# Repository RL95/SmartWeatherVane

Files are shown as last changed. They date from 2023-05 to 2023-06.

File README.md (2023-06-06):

# Smart Weather Vane (project SAFE)
A smart weather vane used for mounting various sensors on rooftops.

The project was developped at the [The University of Applied Sciences and Arts of Western Switzerland](https://www.hesge.ch/hepia/groupe/aero-nautique-spatiale)(HEPIA) for the project [SAFE (Simulator of Autonomous Flight Environments)](https://www.hesge.ch/hepia/recherche-developpement/projets-recherche/safe-0), which aims to measure and replicate atmospheric turbulence at drone scale in an autonomous flight environment simulator for drone certification.

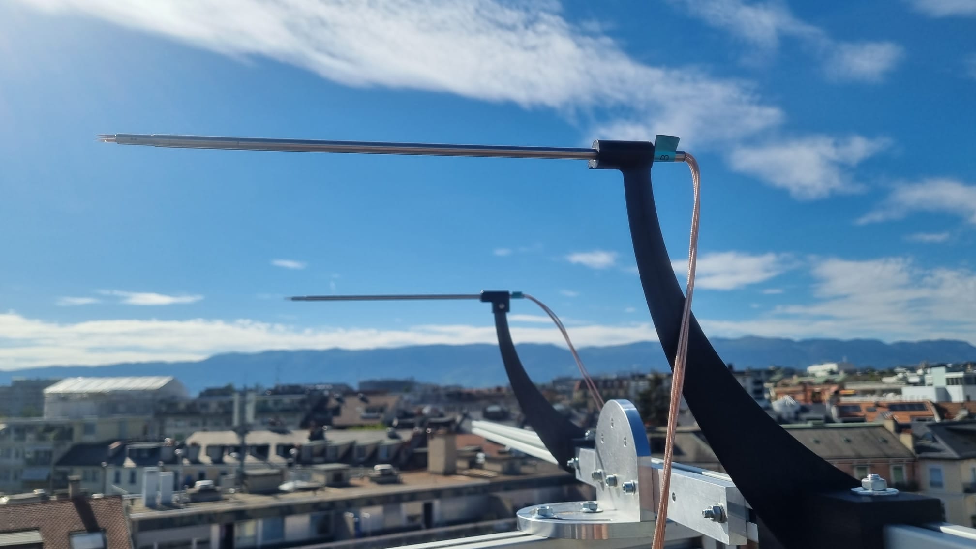
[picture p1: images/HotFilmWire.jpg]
HotFilmWire

(image © M. Jourdain de Thieulloy)

## Firmware
### Description
The control firmware will be running on a NucleoF401RE.

> **Note**
> Firmware implementation is in progress

### Development platform
The firmware is developped with [STM32CUBEIDE](https://www.st.com/en/development-tools/stm32cubeide.html)

### Dependencies
> **Note**
> None for now :)

## Hardware list

|Item|QTY| Ref. Mfr |Ref. Sup. |Supplier |Description/link |
|:--:|:-:|:---:|:---:|:---:|:---:|
|1 |1  |103H7823-5740 |302-23-838 |Distrelec  |[Stepper motor ](https://www.distrelec.ch/en/stepper-motor-7nm-2300min-sup-sup-nema-24-sanyo-denki-103h7823-5740/p/30223838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)|
|2 |1  |PMT-24V200W2BR |303-72-090 |Distrelec  |[SPSU 24V ](https://www.distrelec.ch/en/switched-mode-power-supply-211-2w-24v-8a-delta-electronics-pmt-24v200w2br/p/30372090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)|
|3 |1  |B14HD-L-254-B-4 |301-34-501 |Distrelec  |[Solenoid ](https://www.distrelec.ch/en/metric-pull-latching-open-frame-solenoid-24vdc-22w-12-7mm-27-5ohm-ledex-b14hd-254/p/30134501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)|
|4 |1  |TMC2660-BOB |301-62-143 |Distrelec  |[TMC2660 Driver ](https://www.distrelec.ch/en/stepper-driver-breakout-board-for-tmc2660-28v-trinamic-tmc2660-bob/p/30162143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)|
|5 |1  |ICK SMD F 10 SA |175-58-893 |Distrelec  |[Heatsink ](https://www.distrelec.ch/en/heat-sink-smd-71-fischer-elektronik-ick-smd-10-sa/p/17558893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)|
|6 |1  |N/A |22004-052512 |Norelem |[Pulley HTD 5M 12t ](https://www.norelem.ch/ch/en/Products/Product-overview/Systems-and-components-for-machine-and-plant-construction/Drive-technology/Toothed-belt-pulleys-Splined-shaft-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)|
|7 |1  |N/A |22004-052540 |Norelem |[Pulley HTD 5M 40t ](https://www.norelem.ch/ch/en/Products/Product-overview/Systems-and-components-for-machine-and-plant-construction/Drive-technology/Toothed-belt-pulleys-Splined-shaft-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)|
|8 |2  |N/A |24200-35207 |Norelem |[Mounted Bearing UC 207 ](https://www.norelem.ch/ch/en/Products/Product-overview/Systems-and-components-for-machine-and-plant-construction/Trapezoidal-thread-spindles-Ball-screw-linear-actuat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)|
|9 |1  |N/A |22062-0525X0300 |Norelem |[Belt HTD 5M 300mm ](https://www.norelem.ch/ch/en/Products/Product-overview/Systems-and-components-for-machine-and-plant-construction/Drive-technology/Toothed-belt-pulleys-Splined-shaft-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)|
|10  |1  |985-AS5048A-TS_EK_AB |AS5048A-TS_EK_AB |Mouser |[AS5048A hall encoder ](https://www.mouser.ch/ProductDetail/ams-OSRAM/AS5048A-TS_EK_AB?qs=Rt6VE0PE%2FOd5D%2Fkw9O7ofA%3D%3D)|
|11  |1  |N/A |633145 |Galaxus |[Disc brake disc & caliper ](https://www.galaxus.ch/en/s3/product/avid-ball-bearing-5-front-wheel-brake-disc-brakes-633145)|

> **Note**
> Nucleo F401RE must be added to table
>
> **Note**
> Aluminium extrusion used are yet to be listed in the table above
>
> **Note**
> Dibond plate must be added or replaced

## Preview of current CAD design
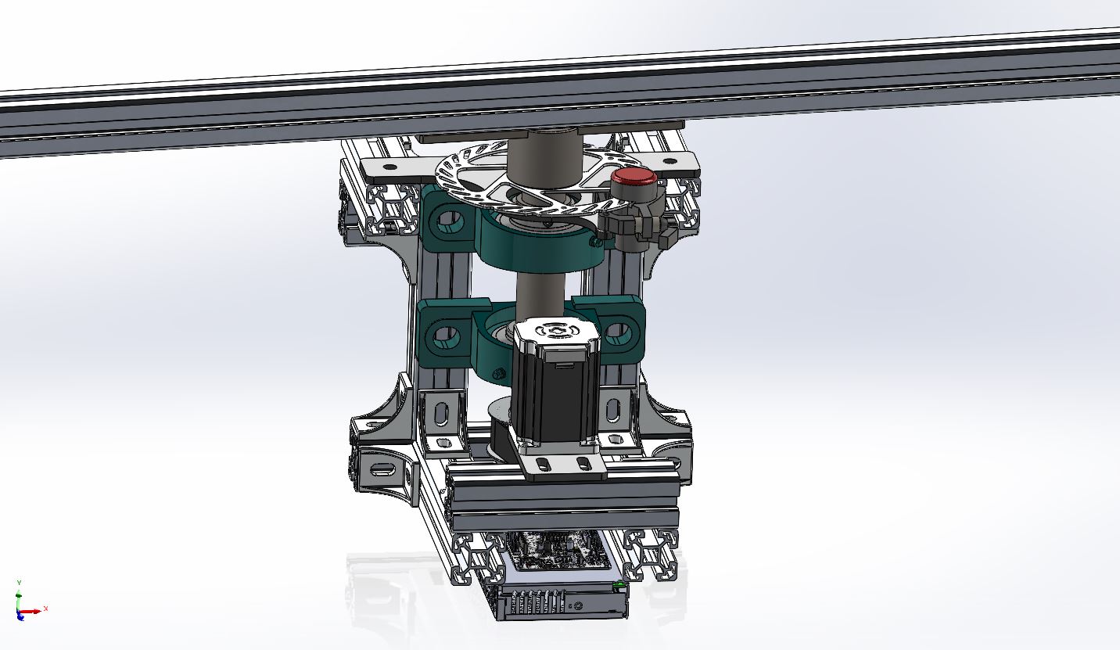
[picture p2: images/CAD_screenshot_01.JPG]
CAD_screenshot1


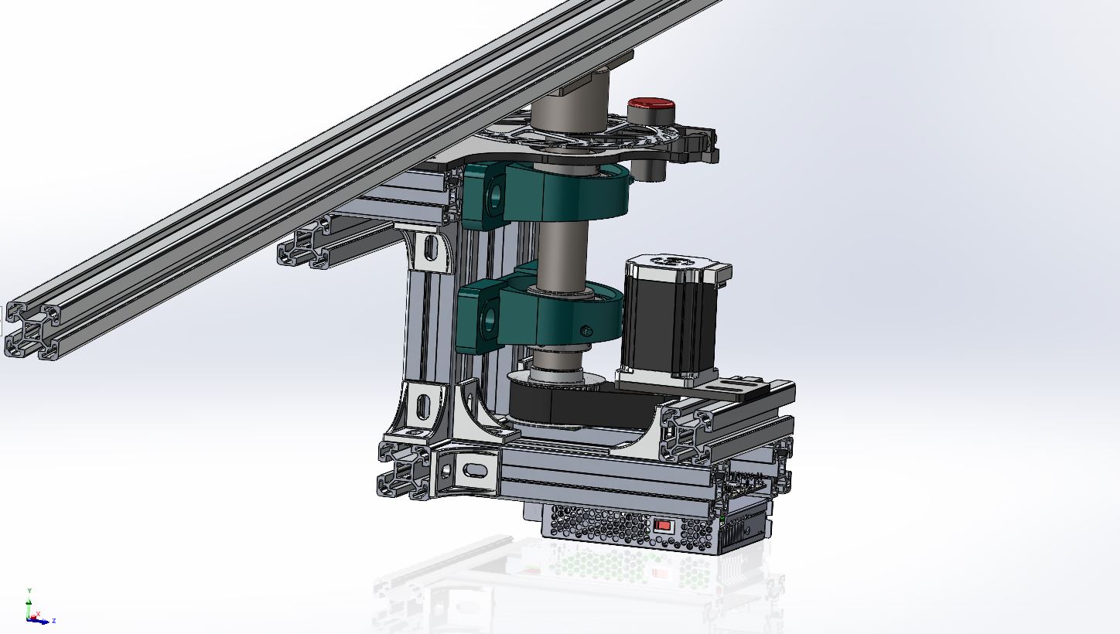
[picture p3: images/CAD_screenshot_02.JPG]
CAD_screenshot2


## TO DO
> **Warning**
> Current design using 40x40 aluminium extrusions, must be changed to 45x45

- [X] Order stuff
- [X] Initial design
  - [X] Change 40x40 to 45x45
- [ ] Firmware stuff 
  - [X] Write AS5048A driver
  - [X] Write TMC6062 driver
  - [X] Setup intial Serial output
  - [X] Setup live graph in IDE
  - [ ] Setup simple TKinter GUI
  - [X] Setup COM port
  - [ ] Setup Python module
- [ ] Mechanical stuff
  - [X] Solenoid brake system 
  - [X] Cut extrusions
  - [ ] Assembly

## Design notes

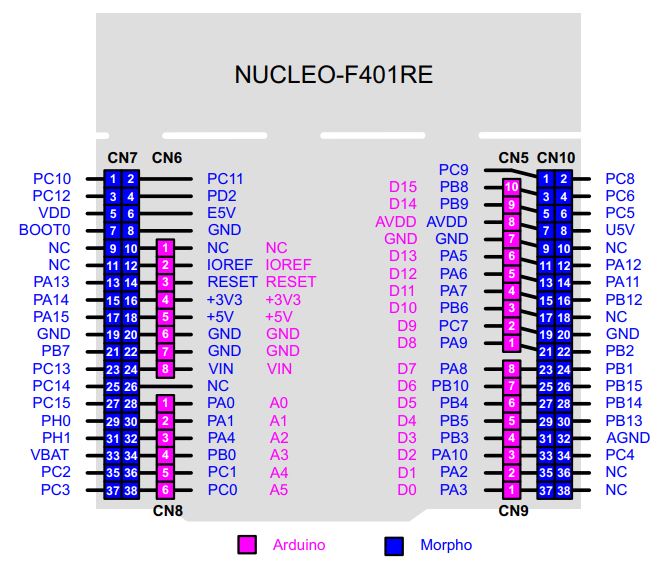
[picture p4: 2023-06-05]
images/nucleoF401RE.JPG

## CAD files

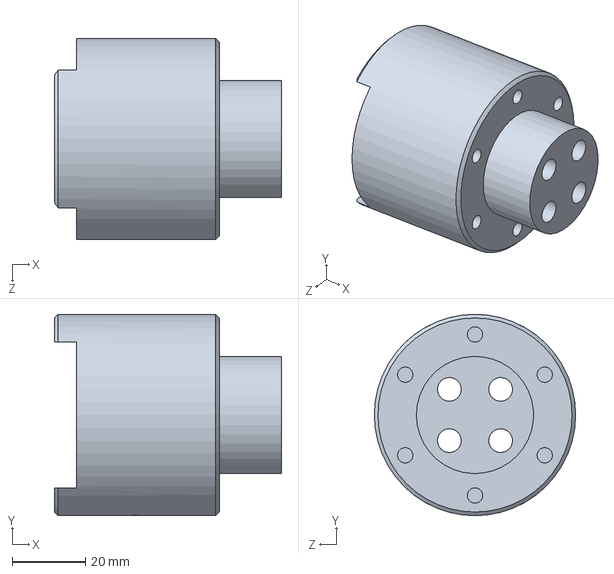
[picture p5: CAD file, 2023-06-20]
CAD/SolidWorks/MainShaftCoupler.SLDPRT
62.0 x 55.0 x 55.0 mm

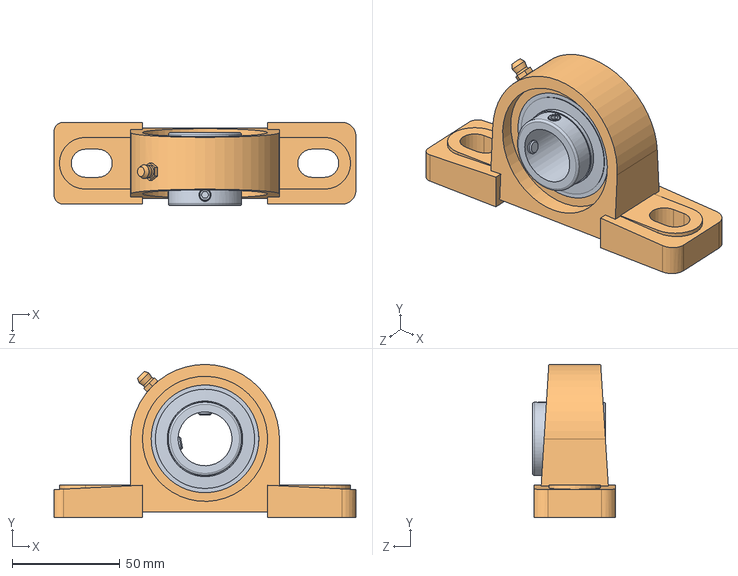
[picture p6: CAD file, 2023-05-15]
CAD/SolidWorks/MountedBearingUC205.SLDASM
140.0 x 71.0 x 38.7 mm
24200_lagerucUC 205.stp
24200_gehaueseP 205.stp

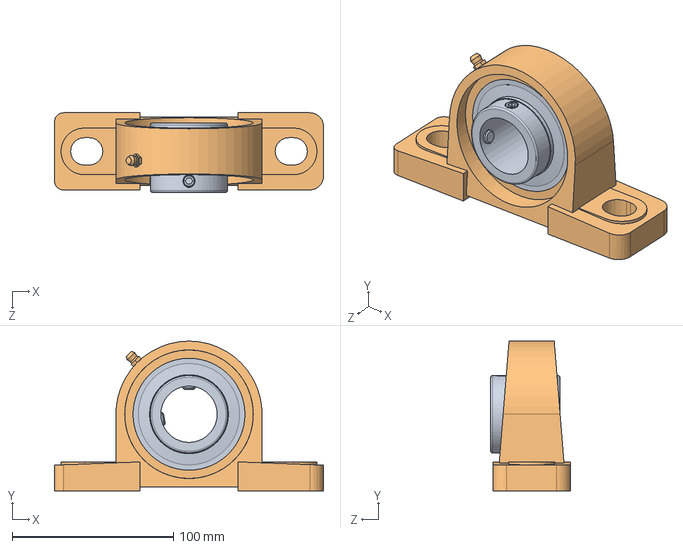
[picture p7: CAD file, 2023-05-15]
CAD/SolidWorks/MountedBearingUC207.SLDASM
167.0 x 93.0 x 49.4 mm
24200_lagerucUC 207.stp
24200_gehaueseP 207.stp

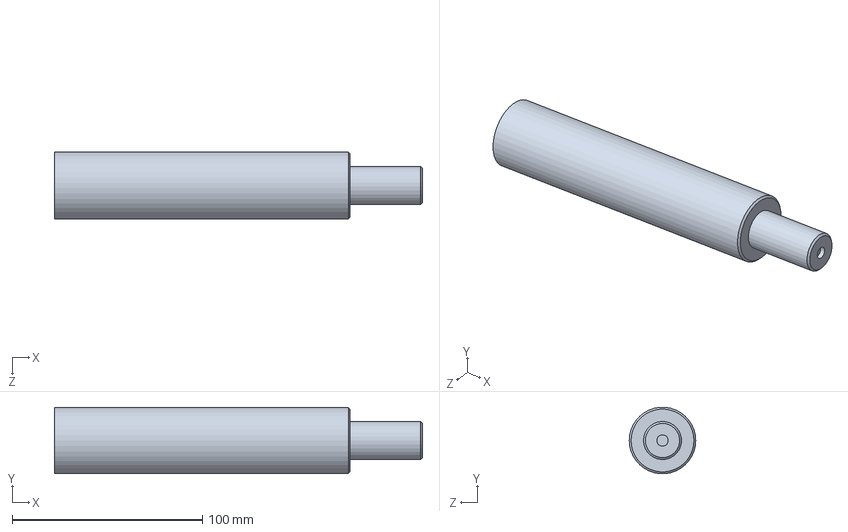
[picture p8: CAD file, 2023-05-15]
CAD/SolidWorks/MainShaft.SLDPRT
193.4 x 34.9 x 35.0 mm

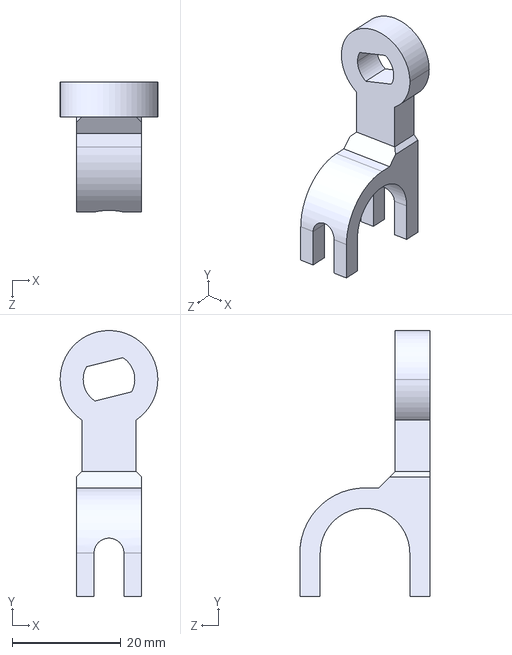
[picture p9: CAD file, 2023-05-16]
CAD/STEP/LeverArm.STEP
18.0 x 49.0 x 24.0 mm

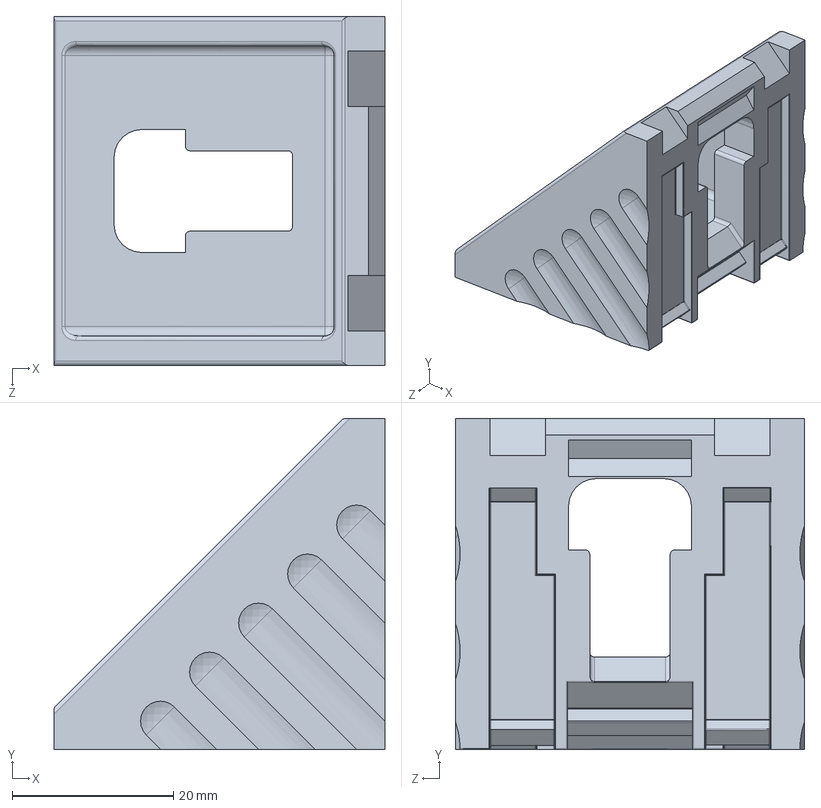
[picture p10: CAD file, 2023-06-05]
CAD/SolidWorks/45x45xbracket.SLDPRT
41.0 x 41.0 x 43.2 mm

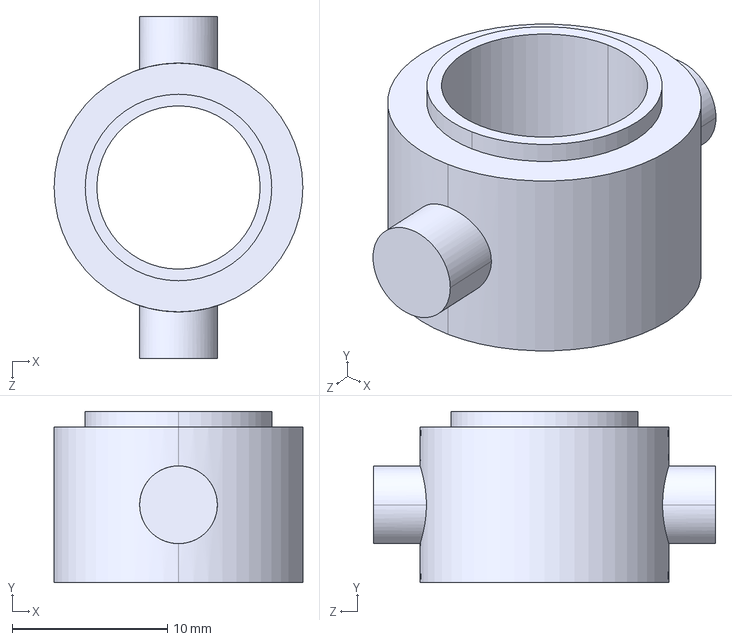
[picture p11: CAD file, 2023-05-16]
CAD/STEP/slider.STEP
16.0 x 11.0 x 22.0 mm

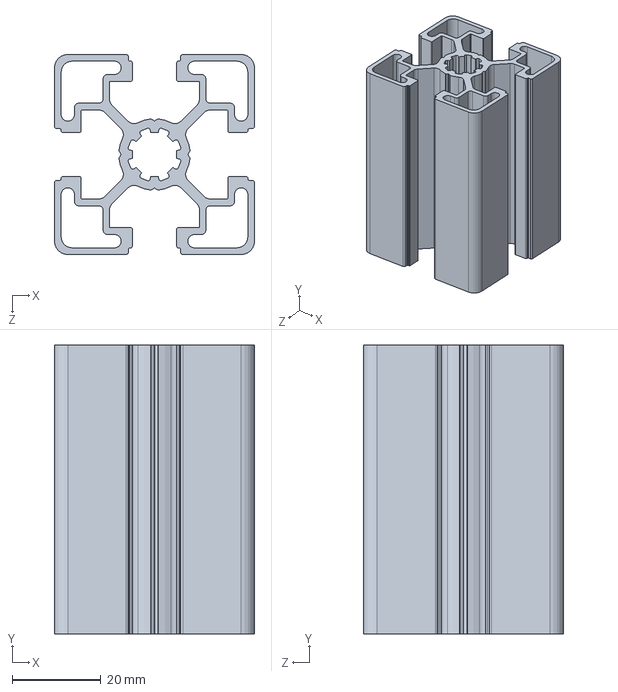
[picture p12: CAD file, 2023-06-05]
CAD/SolidWorks/45x45x95.SLDPRT
45.0 x 65.0 x 45.0 mm

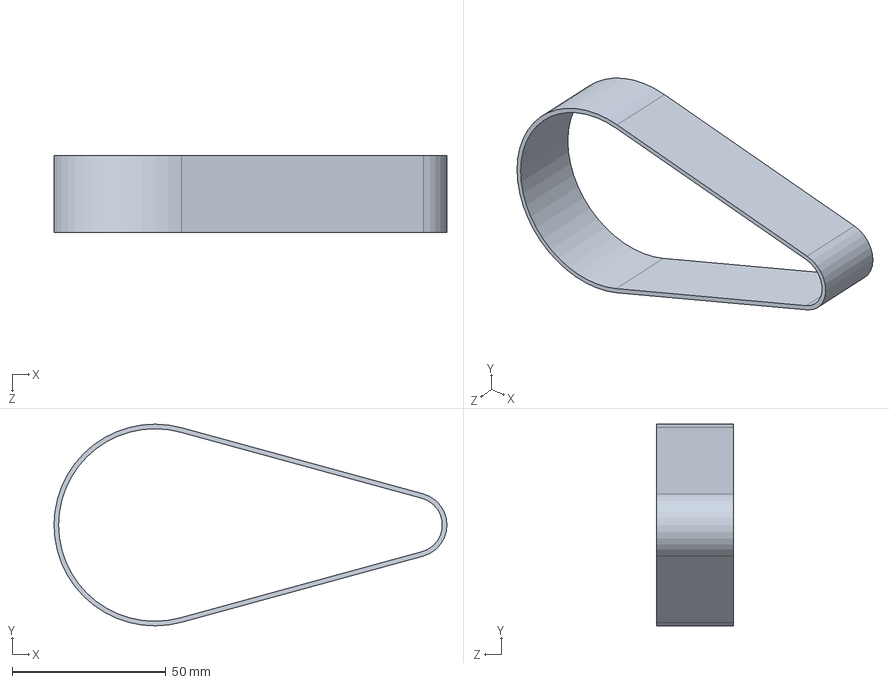
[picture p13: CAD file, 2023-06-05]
CAD/SolidWorks/BeltHTD5M.SLDPRT
127.6 x 65.5 x 25.0 mm

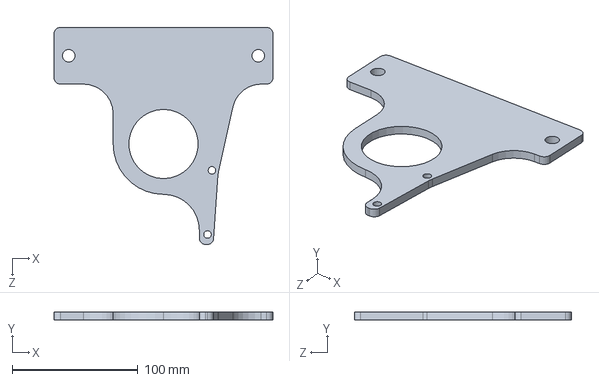
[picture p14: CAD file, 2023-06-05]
CAD/SolidWorks/BrakeSupportPlate.SLDPRT
174.0 x 6.00 x 172.5 mm

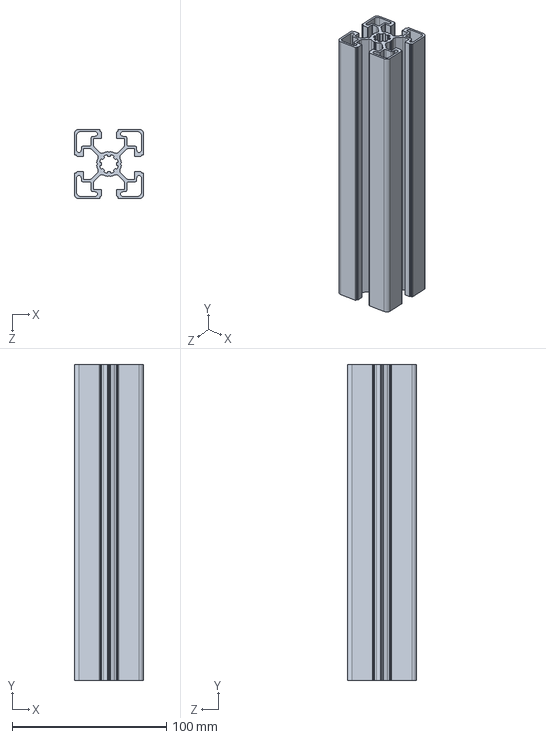
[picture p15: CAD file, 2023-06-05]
CAD/SolidWorks/45x45x300.SLDPRT
45.0 x 205.0 x 45.0 mm

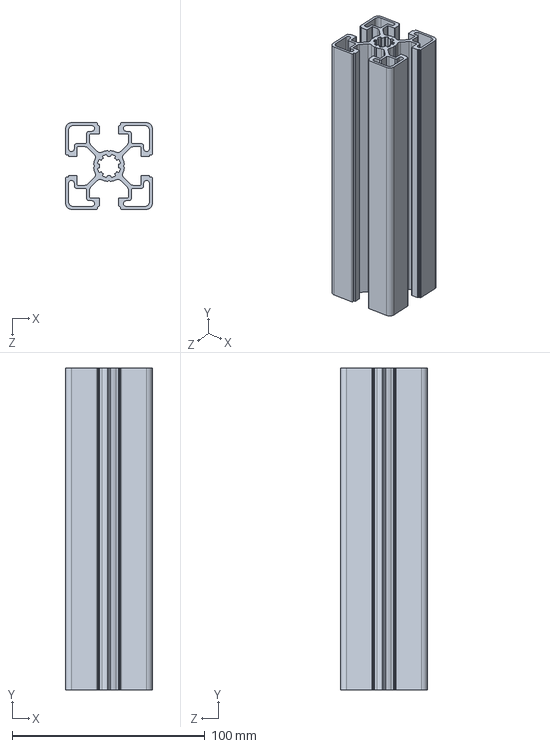
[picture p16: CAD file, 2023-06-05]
CAD/SolidWorks/45x45x174.SLDPRT
45.0 x 167.0 x 45.0 mm

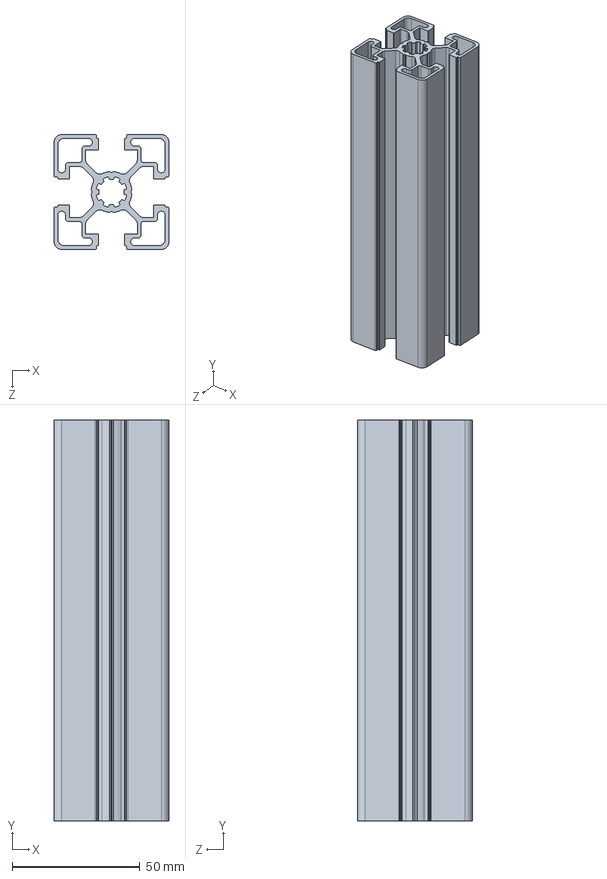
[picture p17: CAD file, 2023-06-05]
CAD/SolidWorks/45x45x160.SLDPRT
45.0 x 157.0 x 45.0 mm

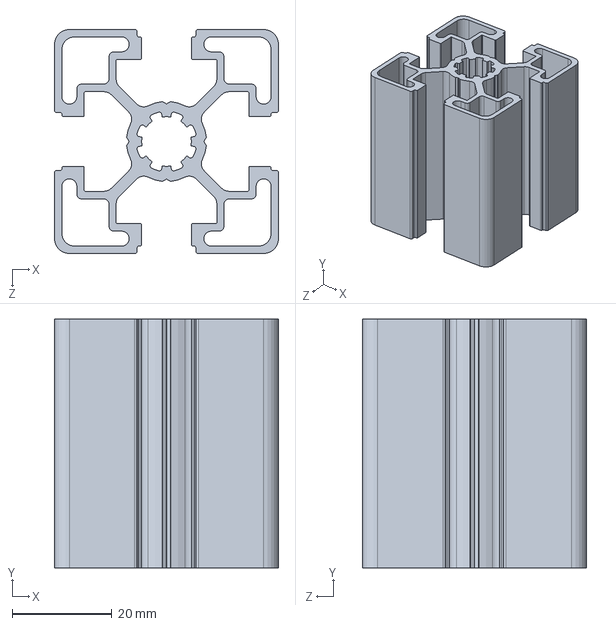
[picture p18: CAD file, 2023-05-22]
CAD/SolidWorks/45x45x50.SLDPRT
45.0 x 50.0 x 45.0 mm

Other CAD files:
CAD/SolidWorks/BrakeSystem/LeverArm.SLDPRT
CAD/SolidWorks/BrakeSystem/slider.SLDPRT
CAD/SolidWorks/SolenoidSupport.SLDPRT
CAD/SolidWorks/AvidCaliper.SLDPRT
CAD/STEP/SpringScrewInterface.STEP
CAD/SolidWorks/40x40x125.SLDPRT
CAD/SolidWorks/40x40x167.SLDPRT
CAD/SolidWorks/40x40x200.SLDPRT
CAD/SolidWorks/40x40x247.SLDPRT
CAD/SolidWorks/40x40x3000.SLDPRT
CAD/SolidWorks/AS5048A-EK-AB.SLDPRT
CAD/SolidWorks/AvidCaliperSupport.SLDPRT
CAD/SolidWorks/AvidDisc160mm.SLDPRT
CAD/SolidWorks/BrakeSystem/ScrewSolenoidInterface.SLDPRT
CAD/SolidWorks/BrakeSystem/SpringScrewInterface.SLDPRT
CAD/SolidWorks/DRV8825.SLDPRT
CAD/SolidWorks/MainShaft.SLDDRW
CAD/SolidWorks/MainShaftCoupler.SLDDRW
CAD/SolidWorks/MotorMountingPlate.SLDPRT
CAD/SolidWorks/NEMA23-Motor-Mounting-Plate.SLDPRT
CAD/SolidWorks/NORELEM_22004052512/22004-052512.stp
CAD/SolidWorks/PulleyHTD3M14T.SLDPRT
CAD/SolidWorks/PulleyHTD3M44T.SLDPRT
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

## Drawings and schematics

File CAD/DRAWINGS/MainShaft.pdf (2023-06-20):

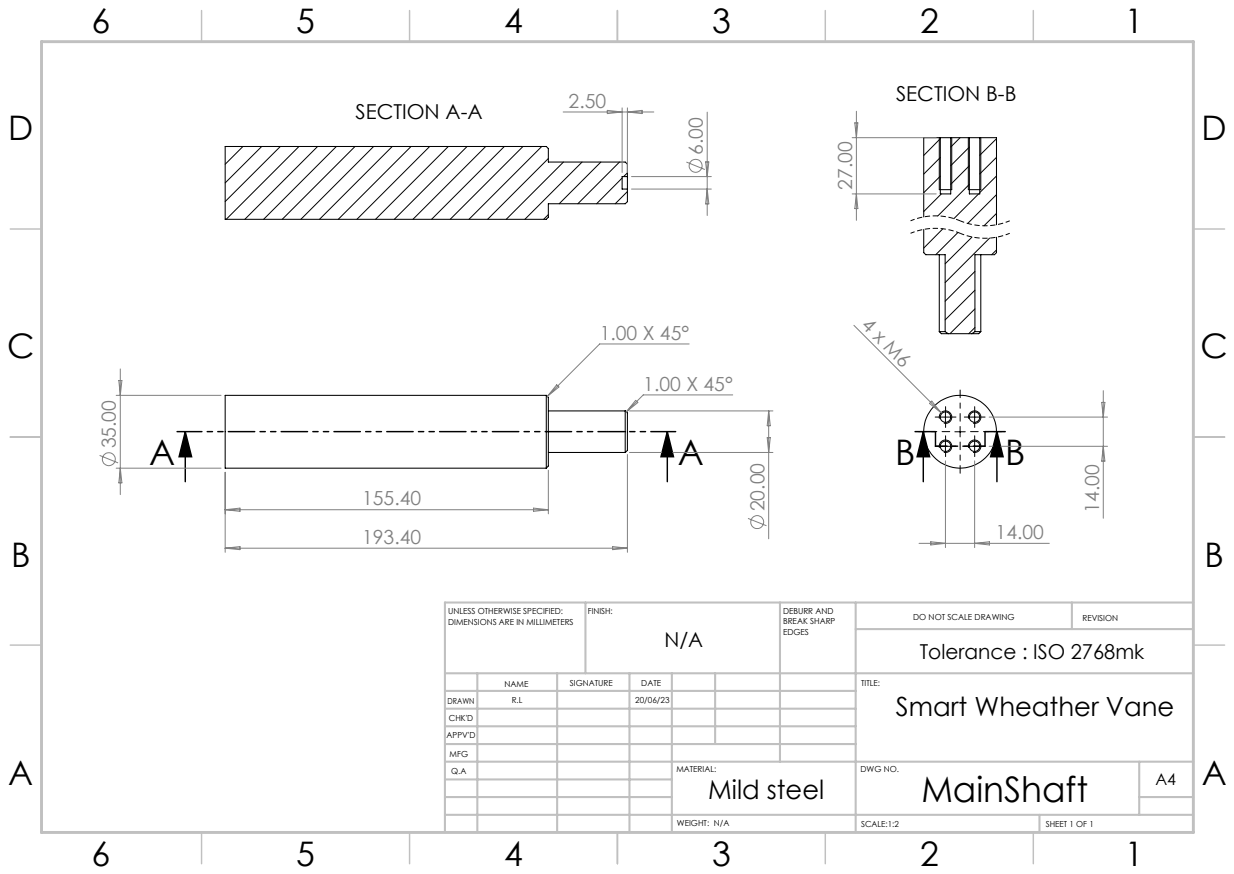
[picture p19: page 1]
2.50 SECTION A-A; SECTION B-B; FINISH:; DEBURR AND; BREAK SHARP; DO NOT SCALE DRAWING; REVISION; SCALE:1:2; SHEET 1 OF 1; Tolerance : ISO 2768mk; WEIGHT: N/A

UNLESS OTHERWISE SPECIFIED:
DIMENSIONS ARE IN MILLIMETERS

NAME | SIGNATURE | DATE | | | | TITLE: Smart Wheather Vane

DRAWN | R.L | | 20/06/23
CHK'D
APPV'D
MFG
Q.A | | | | MATERIAL: Mild steel | DWG NO. | A4 MainShaft

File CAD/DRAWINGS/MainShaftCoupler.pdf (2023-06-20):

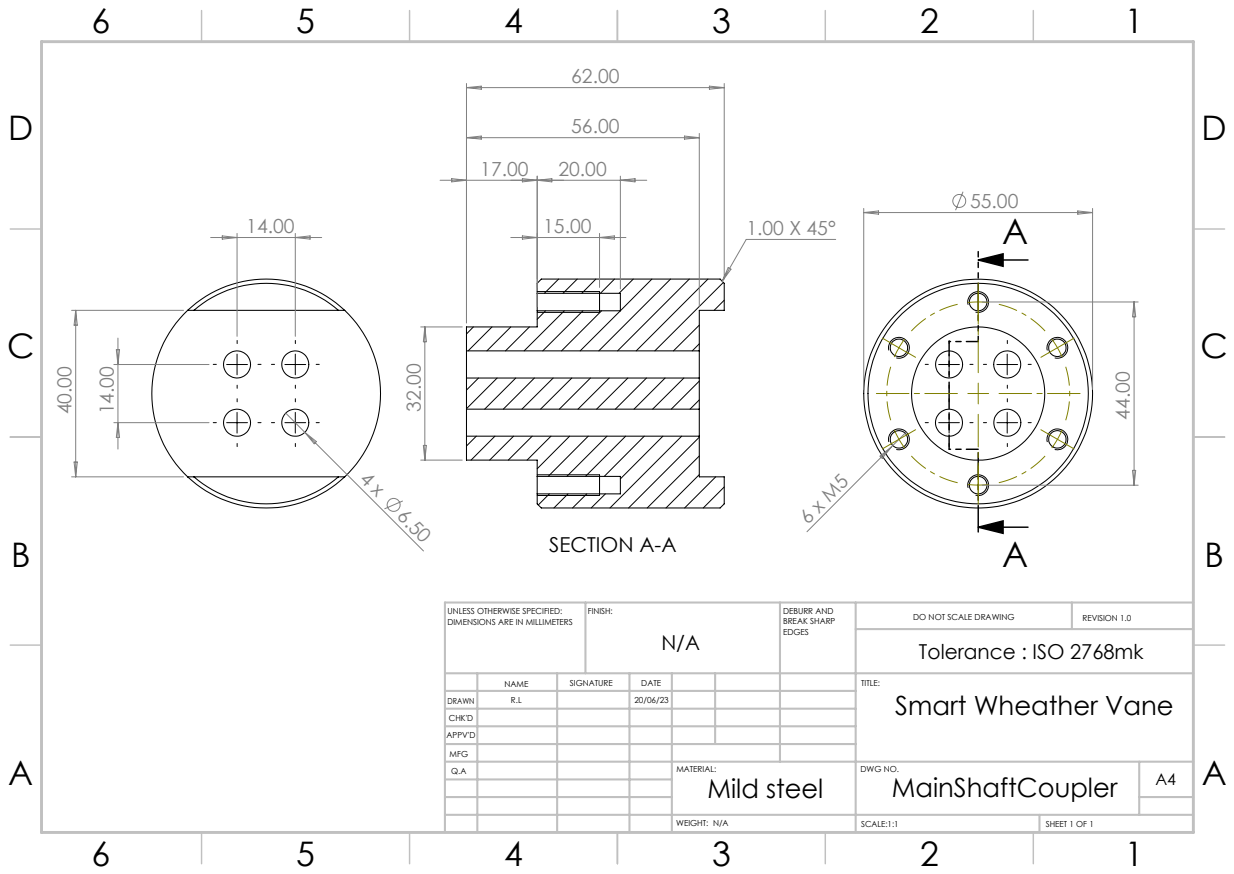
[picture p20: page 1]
SECTION A-A; FINISH:; DEBURR AND; BREAK SHARP; DO NOT SCALE DRAWING; REVISION 1.0; SCALE:1:1; SHEET 1 OF 1; WEIGHT: N/A; Tolerance : ISO 2768mk

UNLESS OTHERWISE SPECIFIED:
DIMENSIONS ARE IN MILLIMETERS

NAME | SIGNATURE | DATE | | | | TITLE: Smart Wheather Vane

DRAWN | R.L | | 20/06/23
CHK'D
APPV'D
MFG
Q.A | | | | MATERIAL: Mild steel | DWG NO. MainShaftCoupler | A4

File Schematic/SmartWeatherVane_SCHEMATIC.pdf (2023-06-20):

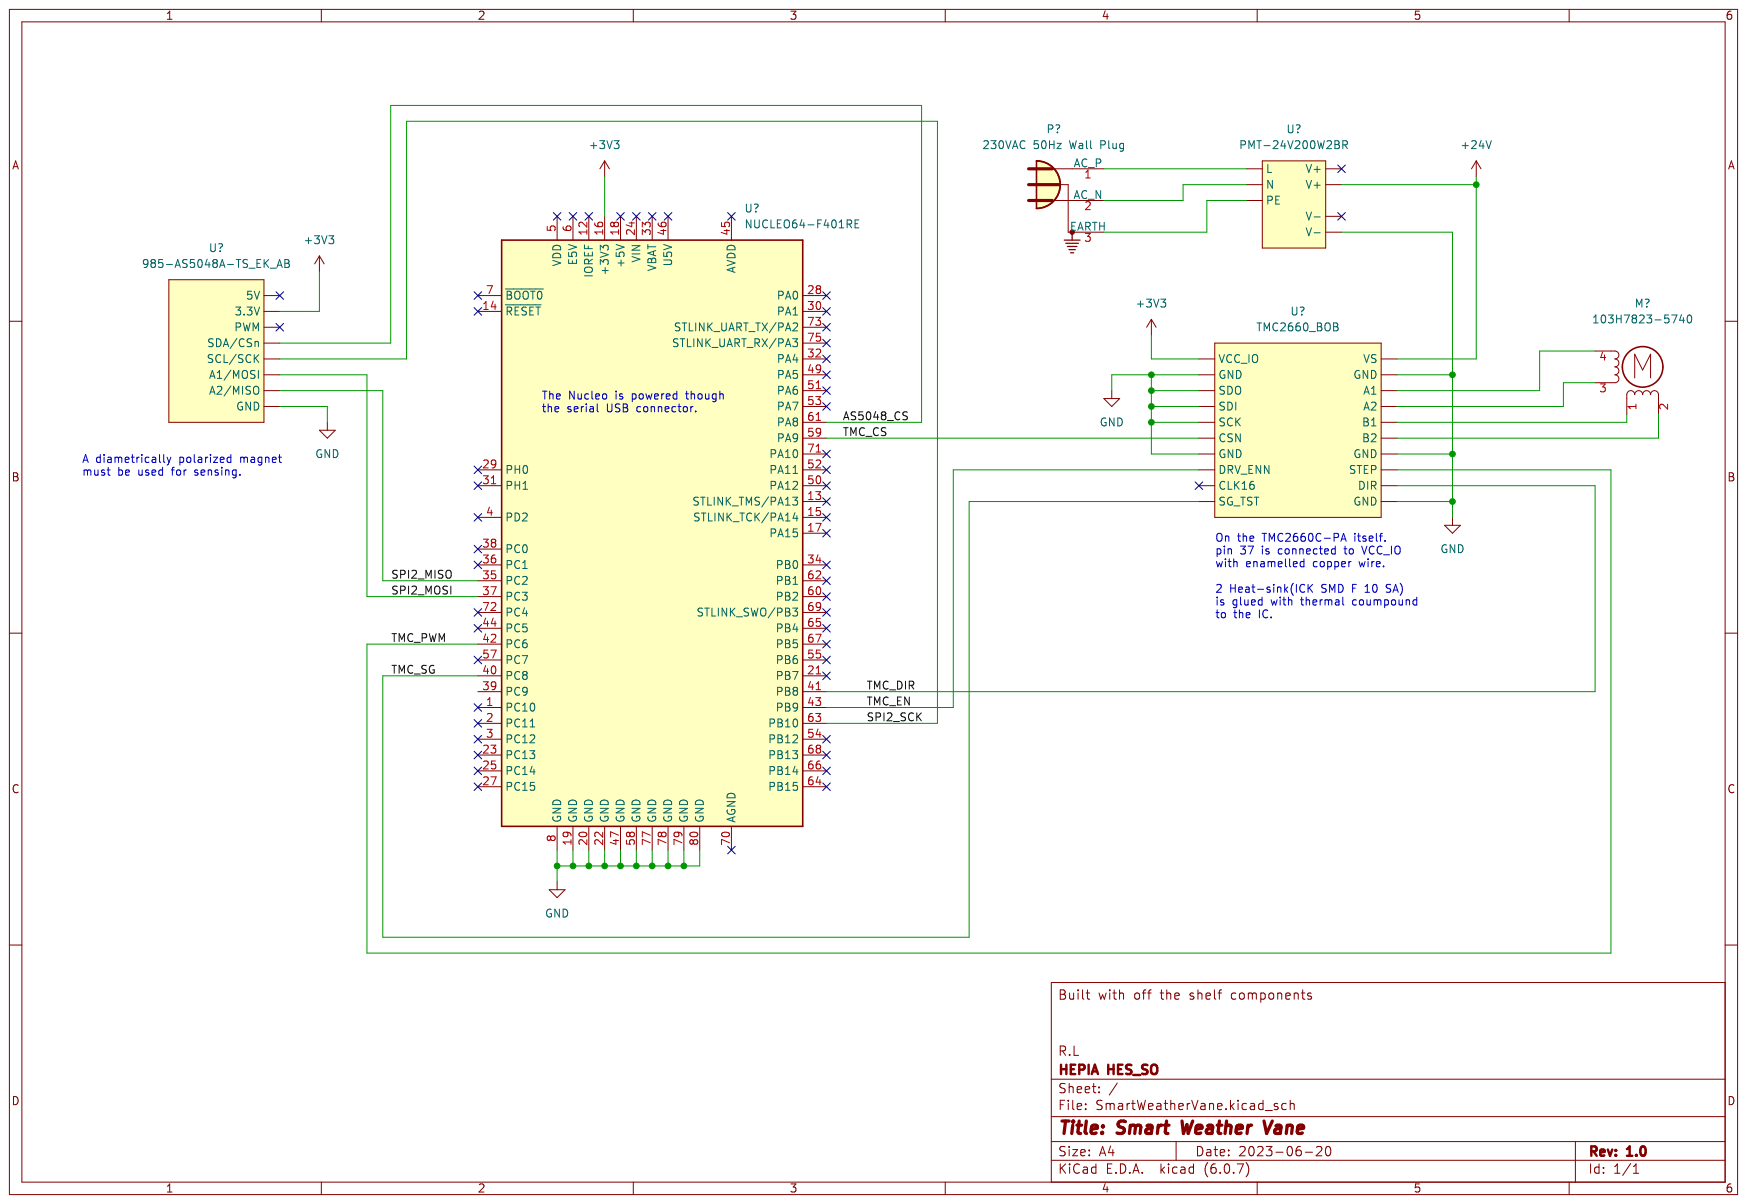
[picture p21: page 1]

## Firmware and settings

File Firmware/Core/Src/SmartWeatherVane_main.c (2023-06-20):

/*
 * SmartWeatherVane_main.c
 *
 *  Created on: 22 May 2023
 *      Author: R.Lin
 */

#include "SmartWeatherVane_main.h"

TMC Motor;
float cmd_angle = 0;

/**
  * @brief  Master Rx Transfer completed callback.
  * @param  hi2c Pointer to a I2C_HandleTypeDef structure that contains
  *                the configuration information for the specified I2C.
  */
void SmartWeatherVane_main(){

	// initialise Stepper motor
	TMC_init(&Motor);

	// initialise FSM
	init_FSM();

	// initialise uart communication
	UART_init();

	// settling time
	HAL_Delay(1000);

	// send startup messages
	UART_send_start_msg();
	UART_send_instruction_msg();

	// start 19kHz timer callback
	Timer_Callback_START();

	//TMC_test_run();

	// super-loop
	while(1){}
}

/**
  * @brief  TIM10 callback running @ 10Hz
  */
void Timer_Callback_10Hz(){
	// send sensor angle if stream requested
	step_FSM_sendval();
}

/**
  * @brief  TIM11 callback running @ 1kHz
  */
void Timer_Callback_1kHz(){
	step_FSM_menu();
	update_current_angle();
	step_FSM_retval();
	cmd_angle = get_FSM_target_angle();
	TMC_move_to(cmd_angle, get_current_angle(), 8000);
}


int _write(int file, char *ptr, int len)
{
	for (int i = 0; i < len; i++){
		ITM_SendChar(*ptr++);
	}
	return len;
}

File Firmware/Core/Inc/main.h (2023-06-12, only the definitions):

#define B1_Pin GPIO_PIN_13
#define B1_GPIO_Port GPIOC
#define USART_TX_Pin GPIO_PIN_2
#define USART_TX_GPIO_Port GPIOA
#define USART_RX_Pin GPIO_PIN_3
#define USART_RX_GPIO_Port GPIOA
#define LD2_Pin GPIO_PIN_5
#define LD2_GPIO_Port GPIOA
#define TMC_PWM_Pin GPIO_PIN_6
#define TMC_PWM_GPIO_Port GPIOC
#define TMC_SG_Pin GPIO_PIN_8
#define TMC_SG_GPIO_Port GPIOC
#define TMC_STEP_Pin GPIO_PIN_9
#define TMC_STEP_GPIO_Port GPIOC
#define AS5048_CS_Pin GPIO_PIN_8
#define AS5048_CS_GPIO_Port GPIOA
#define TMC_CS_Pin GPIO_PIN_9
#define TMC_CS_GPIO_Port GPIOA
#define TMS_Pin GPIO_PIN_13
#define TMS_GPIO_Port GPIOA
#define TCK_Pin GPIO_PIN_14
#define TCK_GPIO_Port GPIOA
#define SWO_Pin GPIO_PIN_3
#define SWO_GPIO_Port GPIOB
#define TMC_DIR_Pin GPIO_PIN_8
#define TMC_DIR_GPIO_Port GPIOB
#define TMC_EN_Pin GPIO_PIN_9
#define TMC_EN_GPIO_Port GPIOB

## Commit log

2023-05-15 update CAD files
    [AvidCaliper.SLDPRT, BeltHTD5M.SLDPRT, BrakeSupportPlate.SLDPRT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]
2023-05-15 Enabled timer and SPI peripheral
2023-05-16 added CAD file
    [SolenoidSupport.SLDPRT, SolenoidSupport.STEP]
2023-05-16 CAD update brake system
    [LeverArm.SLDPRT, LeverArm.STEP, ScrewSolenoidInterface.SLDPRT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]
2023-05-22 added 45x45 base file
    [45x45x50.SLDPRT]
2023-05-22 update cad
    [45x45x157.SLDPRT, 45x45x167.SLDPRT, 45x45x205.SLDPRT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]
2023-06-05 update to 45x45 CAD
    [4040_bracket_s.SLDPRT, 40x120.ipt.stp, 40x160.ipt.stp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]
2023-06-05 added AS5048A driver
2023-06-06 added TMC pin def
2023-06-06 added new files for TMC driver
2023-06-06 initial TMC2660 files
    [Register_summary.xlsx]
2023-06-12 send angle with uart
2023-06-12 added pwm driver and comments
2023-06-12 added initial pwm functions
2023-06-12 added variable frequncy PWM
2023-06-13 added initial motion profiling files
    [Jerk_limited.xlsx]
2023-06-19 added uart communication
2023-06-19 moved angle stream to timer callback
2023-06-19 changed stream rate to 10Hz
2023-06-19 added separate 10kHz timer callback
2023-06-19 setup brake control
2023-06-20 update print string
2023-06-20 added schematic
    [SmartWeatherVane.kicad_pcb, SmartWeatherVane.kicad_sch]
2023-06-20 update CAD & drawings
    [MainShaft.SLDDRW, MainShaftCoupler.SLDDRW, MainShaftCoupler.SLDPRT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]

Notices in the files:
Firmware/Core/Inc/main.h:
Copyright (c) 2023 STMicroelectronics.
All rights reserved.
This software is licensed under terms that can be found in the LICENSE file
